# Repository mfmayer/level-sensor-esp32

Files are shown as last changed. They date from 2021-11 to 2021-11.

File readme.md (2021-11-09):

# esp32-level-sensor

This project is used to read a level sensor (water / fuel) that has different discrete resistance values depending on the height of the float and provide them via Bluetooth Low Energy (Bluetooth LE) advertisement messages.

Completely assembled sensor and tube in which the sensor shall be put:

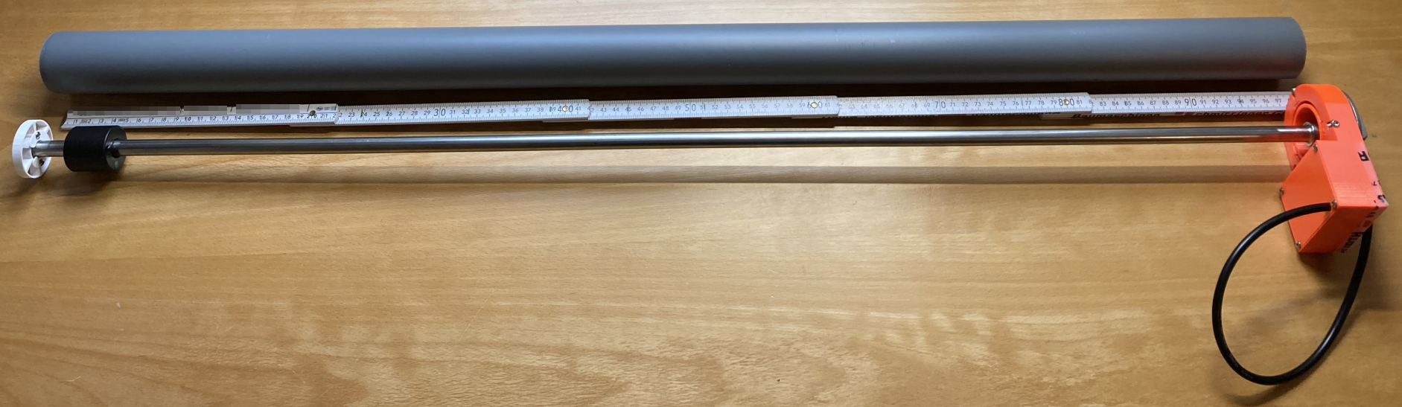
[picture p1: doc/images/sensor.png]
Completely assembled Sensor


## Microcontroller Board

As microcontroller board the Firebeetle ESP32 has been chosen, because it's cheap, it supports Bluetooth Low Energy and it needs ultra low power in hibernate sleep mode, in which only the RTC is powered and power consumption goes down to 0.008 mA.

See also: <https://diyi0t.com/reduce-the-esp32-power-consumption/>

The board gets powered with a Lithium CR123 battery.

## Sensor

It was crucial to get a reliable and robust level measurement, so I've decided not to use ultra sonic sensors or similar but a sensor with a float and reed switches that switch different resistors at different heights from 240 Ω at the min height and 30 Ω at the max height.

## Case and Spacer

The case at the top and spacer at the bottom are designed in FreeCAD and printed with a filament 3d printer.

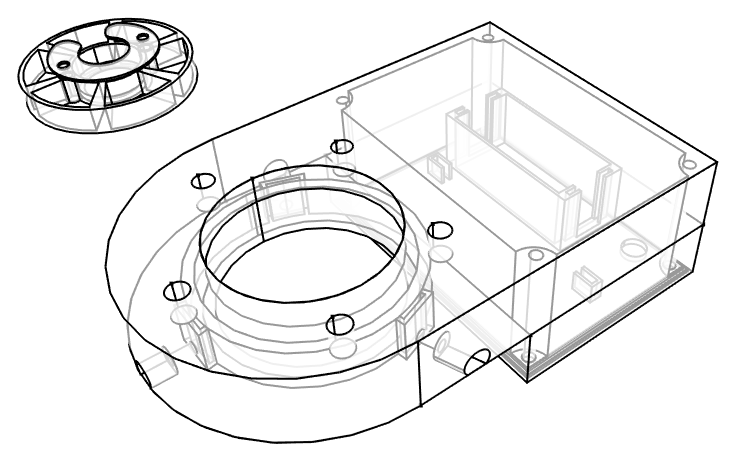
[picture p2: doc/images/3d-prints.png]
Case and Spacer


## Schematic

Via an ESP32's ADCs and voltage dividers the sensor as well as the battery voltage is measured. Sensor reading is put in relation to battery voltage reading to reduce influence of decreasing battery voltage over the time.

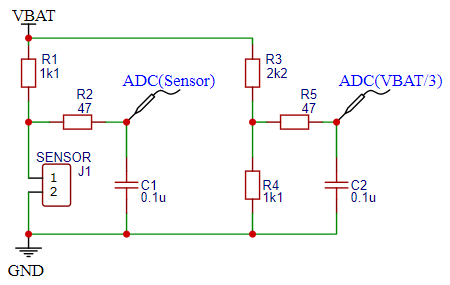
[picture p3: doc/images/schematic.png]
Schematic


## Sensor readings

The following table shows the values ADC(Sensor) / ADC(VBAT/3) and according sensor height that have been manually read and measured. Based on that I've derived sections with linear interpolation in between:

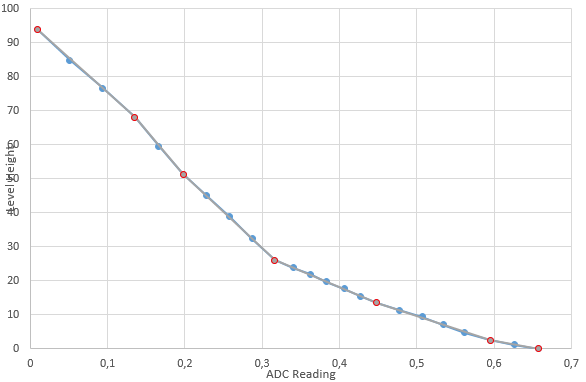
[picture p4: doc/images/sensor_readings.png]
sensor readings


To compute interpolating polymomial, WolframAlpha's [interpolating polynomial calculator](https://www.wolframalpha.com/input/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) was a great help:

| Height [cm] | ADC(Sensor) / ADC(VBAT/3) | Linearization points |
| --- | --- | --- |
| 0 | 0,658 | linear fit {{0.658, 0}, {0.595, 2.5}} |
| 1,1 | 0,626 | |
| 2,5 | 0,595 | linear fit {{0.595, 2.5}, {0.448, 13.4}}  |
| 4,6 | 0,562 | |
| 7 | 0,534 | |
| 9,3 | 0,507 | |
| 11,3 | 0,477 | |
| 13,4 | 0,448 | linear fit {{0.448, 13.4}, {0.316, 25.9}} |
| 15,4 | 0,427 | |
| 17,6 | 0,406 | |
| 19,6 | 0,383 | |
| 21,8 | 0,362 | |
| 23,8 | 0,34 | |
| 25,9 | 0,316 | linear fit {{0.316, 25.9}, {0.198, 51.2}} |
| 32,3 | 0,287 | |
| 38,8 | 0,258 | |
| 45 | 0,228 | |
| 51,2 | 0,198 | linear fit {{0.198, 51.2}, {0.135, 68.1}} |
| 59,5 | 0,166 | |
| 68,1 | 0,135 | linear fit {{0.135, 68.1}, {0.0086, 94}}  |
| 76,5 | 0,0938 | |
| 84,8 | 0,0511 | |
| 94 | 0,0086 | X |

## Software

The sensor wakes up every few minutes to check the height, battery and wakeup cycle. In case the sensor's height is above 0.5 cm or it woke up for more than 8 cycles since last time it sent the readings, it sends them again via Bluetooth Low Energy. Additionally if the hight is above 0.5 cm, the deep sleep time is also decreased to have a higher sampling rate while there is water registered by the sensor.

### Bluetooth Low Energy Advertisements (BLE)

To save battery power the readings shall be provided as manufacturer specific data within sent BLE advertisisements. That way the ESP32 can hibernate again without waiting for a potential incoming connection to read a charactersitic.

For this purpose I've written some helper clases and methods that allow to append sensor readings of integer and float type to a BLE advertisement message.

```cpp
void setup() {
  // read sensor and battery power
  // set txCounter if readings shall be sent in this wake cycle
  // set sleepSeconds how long the ESP32 shall hibernate after this cycle

  if (txCounter > 0) {
    // sensor readings shall be sent in this wake cycle when txCounter > 0
    Ble::DataElements dataElements = {
        Ble::DataElement(wakeupCounter),
        Ble::DataElement(rawFillingLevel),
        Ble::DataElement(fillingLevel),
        Ble::DataElement(rawBatteryStatus),
        Ble::DataElement(normalisedFillingLevelRaw)};

    Ble::advertise(dataElements);
    delay(80); // wait as long as the message is to be sent repeatedly
  }
  wakeupCounter++;
  deepSleep(sleepSeconds);
}
```

### Home Assistant Integration

I've also written a generic BLE Home Assistant custom component that allows to import the sensor readings. I've tried to design that compnent as generic as possible so that multiple advertisements as well as BLE characteristic readings can be configured to be read and decoded appropriately.

See:
<https://github.com/mfmayer/home_assistant_custom_components/tree/main/ble_generic_sensor>

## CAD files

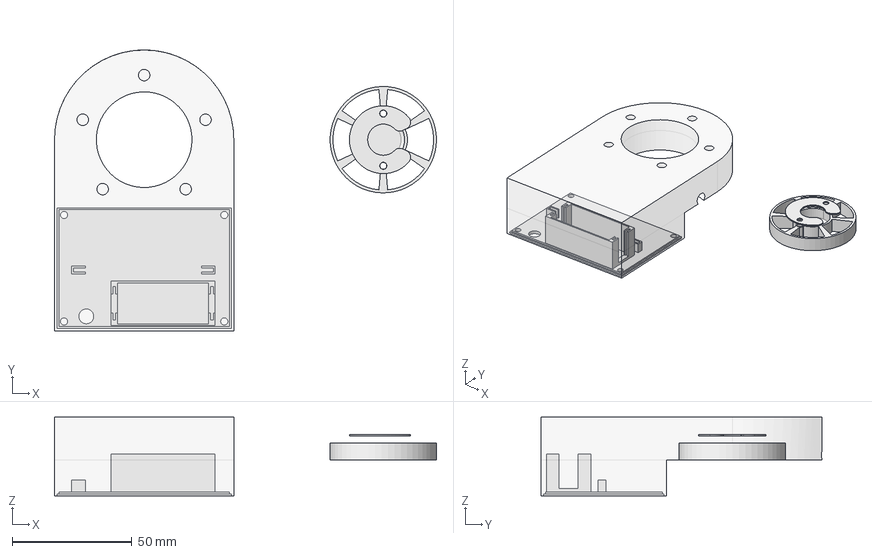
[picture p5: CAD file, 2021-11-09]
cad/level_sensor.FCStd
159.8 x 117.5 x 33.0 mm

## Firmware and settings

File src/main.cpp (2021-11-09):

#include <Arduino.h>

#include "ble.h"
#include "esp32-hal-log.h"

// Prints the reason for wakeup
void print_wakeup_reason() {
  esp_sleep_wakeup_cause_t wakeup_reason;
  wakeup_reason = esp_sleep_get_wakeup_cause();
  switch (wakeup_reason) {
    case ESP_SLEEP_WAKEUP_EXT0:
      log_v("Wakeup caused by external signal using RTC_IO");
      break;
    case ESP_SLEEP_WAKEUP_EXT1:
      log_v("Wakeup caused by external signal using RTC_CNTL");
      break;
    case ESP_SLEEP_WAKEUP_TIMER:
      log_v("Wakeup caused by timer");
      break;
    case ESP_SLEEP_WAKEUP_TOUCHPAD:
      log_v("Wakeup caused by touchpad");
      break;
    case ESP_SLEEP_WAKEUP_ULP:
      log_v("Wakeup caused by ULP program");
      break;
    default:
      log_v("Wakeup was not caused by deep sleep: %d\n", wakeup_reason);
      break;
  }
}

void deepSleep(uint32_t secondsToSleep) {
  // Convert time before wakeup to microseconds
  esp_sleep_enable_timer_wakeup(secondsToSleep * 1000000);
  esp_sleep_pd_config(ESP_PD_DOMAIN_RTC_PERIPH, ESP_PD_OPTION_OFF);
#if CORE_DEBUG_LEVEL >= 5
  log_v("Going to deep-sleep in 5 sec for %d sec\n", secondsToSleep);
  Serial.flush();
#endif
  esp_deep_sleep_start();
}

// adcSample samples given ADC `samples` times and returns the average.
// `dOutPin` is pulled to HIGH while doing so (OUTPUT pin mode must
// have been set before).
uint16_t adcSample(uint8_t aInPin, uint8_t dOutPin, uint16_t samples) {
  uint32_t avg = 0;
  digitalWrite(dOutPin, HIGH);
  for (int i = 0; i < samples; i++) {
    uint16_t a = analogRead(aInPin);
    avg = avg + a;
  }
  digitalWrite(dOutPin, LOW);
  return (avg / samples);
}

// analogToSensorHeight converts `x` (raw adc reading) to level height.
float analogToSensorHeight(float x) {
  float a = 0;
  float b = 0;
  if (x > 0.595) {
    // 26.1111 - 39.6825 x
    a = -39.6825;
    b = 26.1111;
  } else if (x > 0.448) {
    // 46.619 - 74.1497 x
    a = -74.1497;
    b = 46.619;
  } else if (x > 0.316) {
    // 55.8242 - 94.697 x
    a = -94.697;
    b = 55.8242;
  } else if (x > 0.198) {
    // 93.6525 - 214.407 x
    a = -214.407;
    b = 93.6525;
  } else if (x > 0.135) {
    // 104.314 - 268.254 x
    a = -268.254;
    b = 104.314;
  } else {
    // 95.7622 - 204.905 x
    a = -204.905;
    b = 95.7622;
  }
  return a * x + b;
}

uint16_t a[3] = {0, 0, 0};
bool print = false;

void printSensorHeight() {
  a[0] = adcSample(A0, D3, 32);
  float h = analogToSensorHeight(a[0]);
  log_v("****** %d - %f\n", a[0], h);
}

void printBatteryVoltage() {
  uint16_t batteryRaw = adcSample(A3, D4, 32);
  log_v("bat raw: %d", batteryRaw);
}

RTC_DATA_ATTR uint8_t wakeupCounter = 0;
RTC_DATA_ATTR uint8_t txCounter = 0;
RTC_DATA_ATTR uint16_t lastSentRawFillingLevel;
RTC_DATA_ATTR uint16_t lastSentRawBatteryStatus;

void setup() {
#if CORE_DEBUG_LEVEL >= 5
  Serial.begin(115200);
  // wait for serial port to connect. Needed for native USB
  while (!Serial) {
  }
  print_wakeup_reason();  // Print the wakeup reason for ESP32
  log_v("Serial enabled");
#endif

  uint32_t sleepSeconds = 30;

  pinMode(D3, OUTPUT);
  pinMode(D4, OUTPUT);
  analogSetAttenuation(ADC_0db);
  digitalWrite(D3, LOW);  // Spannungsteiler wird über D3 versorgt.
  digitalWrite(D4, LOW);  // Spannungsteiler wird über D3 versorgt.

  uint16_t rawFillingLevel = adcSample(A0, D3, 32);
  uint16_t rawBatteryStatus = adcSample(A3, D4, 32);
  float normalisedFillingLevelRaw = (float)rawFillingLevel / (float)rawBatteryStatus;
  float fillingLevel = analogToSensorHeight(normalisedFillingLevelRaw);
  if (fillingLevel < 0.0) {
    fillingLevel = 0.0;
  } else if (fillingLevel > 94.0) {
    fillingLevel = 94.0;
  }

  if ((wakeupCounter % 8) == 0) {
    if (txCounter <= 0) {
      txCounter = 1;
    }
  }
  if (fillingLevel > 0.5) {
    txCounter = 5;
  }
  if (txCounter > 1) {
    sleepSeconds = 10;
  }

#if CORE_DEBUG_LEVEL >= 5
  log_v("wakeupCounter: %d (wakeupCounter mod 8): %d txCounter: %d sleepSeconds: %d", wakeupCounter, (wakeupCounter % 8), txCounter, sleepSeconds);
#endif

  if (txCounter > 0) {
    // if (true) {
    txCounter--;
    lastSentRawFillingLevel = rawFillingLevel;
    lastSentRawBatteryStatus = rawBatteryStatus;

    float fillingLevel = analogToSensorHeight(normalisedFillingLevelRaw);
    if (fillingLevel < 0.0) {
      fillingLevel = 0.0;
    } else if (fillingLevel > 94.0) {
      fillingLevel = 94.0;
    }

#if CORE_DEBUG_LEVEL >= 5
    log_v("fillingLevel (raw - height)     : %d - %f", rawFillingLevel, fillingLevel);
    log_v("batteryStatus (raw)             : %d", rawBatteryStatus);
    log_v("normalisedFillingLevelRaw (raw) : %f", normalisedFillingLevelRaw);
#endif

    Ble::DataElements dataElements = {
        Ble::DataElement(wakeupCounter),
        Ble::DataElement(rawFillingLevel),
        Ble::DataElement(fillingLevel),
        Ble::DataElement(rawBatteryStatus),
        Ble::DataElement(normalisedFillingLevelRaw)};

    Ble::advertise(dataElements);
    delay(80);
  }
  wakeupCounter++;
  deepSleep(sleepSeconds);
}

void loop() {
}

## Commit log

2021-10-14 fixed voltage divider schematic
2021-11-04 fix serialization refer to power supply voltage reading while calculating water level
    [main.cpp]
2021-11-09 Adding documentation cleaning up code
    [level_sensor.FCStd]
